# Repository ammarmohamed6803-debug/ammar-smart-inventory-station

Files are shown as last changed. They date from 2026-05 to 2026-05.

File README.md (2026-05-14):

📦 Handmade Heroes Inventory Station

A standalone IoT warehouse terminal built on ESP32 — scan, log, and sync inventory in real time without a computer.
🧾 Overview
The Handmade Heroes Inventory Station is a physical inventory management terminal designed for a small cosmetics warehouse. Workers tap their RFID cards, type a product code on a keypad, and log stock movements — all tracked per batch and synced live to Google Sheets.
Built entirely on an ESP32 DevKit V1, with no PC required on the warehouse floor.

✨ Features

🔖 RFID worker authentication — each worker taps their card to start a session
📦 Per-batch inventory tracking — store, ship, or add leftovers per batch number
🔁 Offline queue — transactions saved to flash if WiFi is down, auto-synced on reconnect
📊 Google Sheets integration — every transaction logs to a live spreadsheet via Apps Script
🌐 Web admin panel — edit the product list from any browser on the same network, no reflashing needed
🔒 Supervisor mode — Ammar, Aqilah, and Adi have elevated access to view stock and sync queue
↩️ Undo — reverse the last transaction (reflected on both device and sheet)
🛡️ Stock protection — can't delete a product that still has stock via the web admin
💾 Persistent storage — inventory state survives power cuts (LittleFS binary file)
⏱️ Auto session timeout — 30-minute idle timeout for security

🛠️ Hardware
ComponentDetailsMicrocontrollerESP32 DevKit V1 (30-pin)RFID ReaderRC522 (SPI)Display20×4 I2C LCD (address 0x27)Keypad4×4 matrix keypadLEDsGreen (GPIO 2), Red (GPIO 16)I2C ExpanderPCF8574 (for LCD backpack)
Pin Mapping
RC522 (SPI)
RC522ESP32SSGPIO 5RSTGPIO 4MOSIGPIO 23MISOGPIO 19SCKGPIO 18
LCD I2C
SignalESP32SDAGPIO 21SCLGPIO 22
Keypad Rows/Cols
PinsRows13, 14, 27, 26Cols25, 33, 32, 15

🚀 Getting Started
1. Prerequisites
Install these libraries in Arduino IDE:

MFRC522
LiquidCrystal_I2C
Keypad
WiFiClientSecure
LittleFS (ESP32 built-in)
Preferences (ESP32 built-in)
WebServer (ESP32 built-in)

Board: ESP32 Dev Module via Arduino ESP32 board package
2. Configuration
Edit these lines at the top of the .ino before flashing:
cppconst char* WIFI_SSID     = "YourNetworkName";
const char* WIFI_PASSWORD = "YourPassword";
const char* SHEET_URL     = "https://script.google.com/macros/s/YOUR_SCRIPT_ID/exec";
3. Google Apps Script Setup

Open Google Sheets → create a new spreadsheet
Go to Extensions → Apps Script
Paste your Code.gs and deploy as a Web App

Execute as: Me
Access: Anyone

Copy the deployment URL into SHEET_URL

4. First Boot
On first boot the device will:

Write the default product list to /products.csv on LittleFS
Connect to WiFi and show the IP address on the LCD
Auto-flush any queued offline transactions
Show Station Ready

5. Web Admin — Adding / Editing Products

Note the IP shown on the LCD at boot (e.g. 192.168.1.45)
Open http://192.168.1.45 in any browser on the same network
Edit products in code|name|sku format, one per line
Hit Save & Reload

⚠️ You cannot remove a product that still has stock. Ship it out first.

👷 Worker Roles
NameRoleAmmarSupervisorAqilahSupervisorAdiSupervisorYettiWorkerStevenWorkerStaffWorker
Supervisors get an Admin Panel on login with options to view stock, sync the offline queue, and switch to work mode.

📋 Transaction Types
ActionDescriptionStorageNew stock arriving — enter batch, box color, box qty, piecesShippingStock going out — pick batch, enter pieces to deductAdd LeftoverAdd loose pieces to an existing batch

🔄 Offline Mode
If WiFi is down, transactions are saved to /queue.txt on LittleFS. They auto-flush to Google Sheets on next boot, or manually via the supervisor's Sync Queue option.

🔧 Factory Reset
To wipe all stored data, uncomment this in setup():
cppfactoryReset();
Flash once, then comment it out and reflash. The LCD will instruct you.

📊 Google Sheets Columns
ColumnFieldADate & TimeBProduct ID (SKU)CProduct NameDConditionEBox TypeFNo. of BoxesGNo. of PiecesHTotal QtyIPatch No. (Batch)JWorker Name

📝 Version History
VersionChangesv5Web admin panel, LittleFS batch persistence, undo syncs to Sheets, factory reset, stock protectionv4Per-batch tracking, offline queue, supervisor mode, NVS persistence

📄 License
MIT — free to use and modify. Credit appreciated.

🙏 Acknowledgements
Built for Handmade Heroes — a Malaysian handmade cosmetics brand. Designed to replace manual stock counting with a fast, reliable, offline-capable hardware terminal.

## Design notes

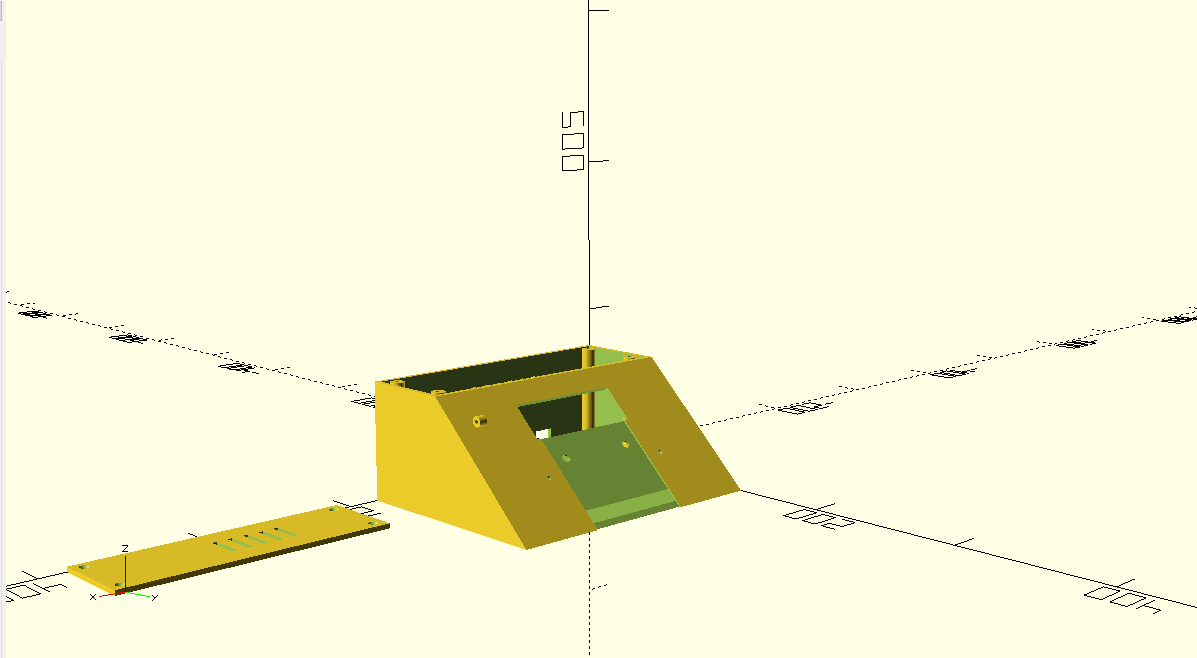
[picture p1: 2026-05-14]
3D design.png

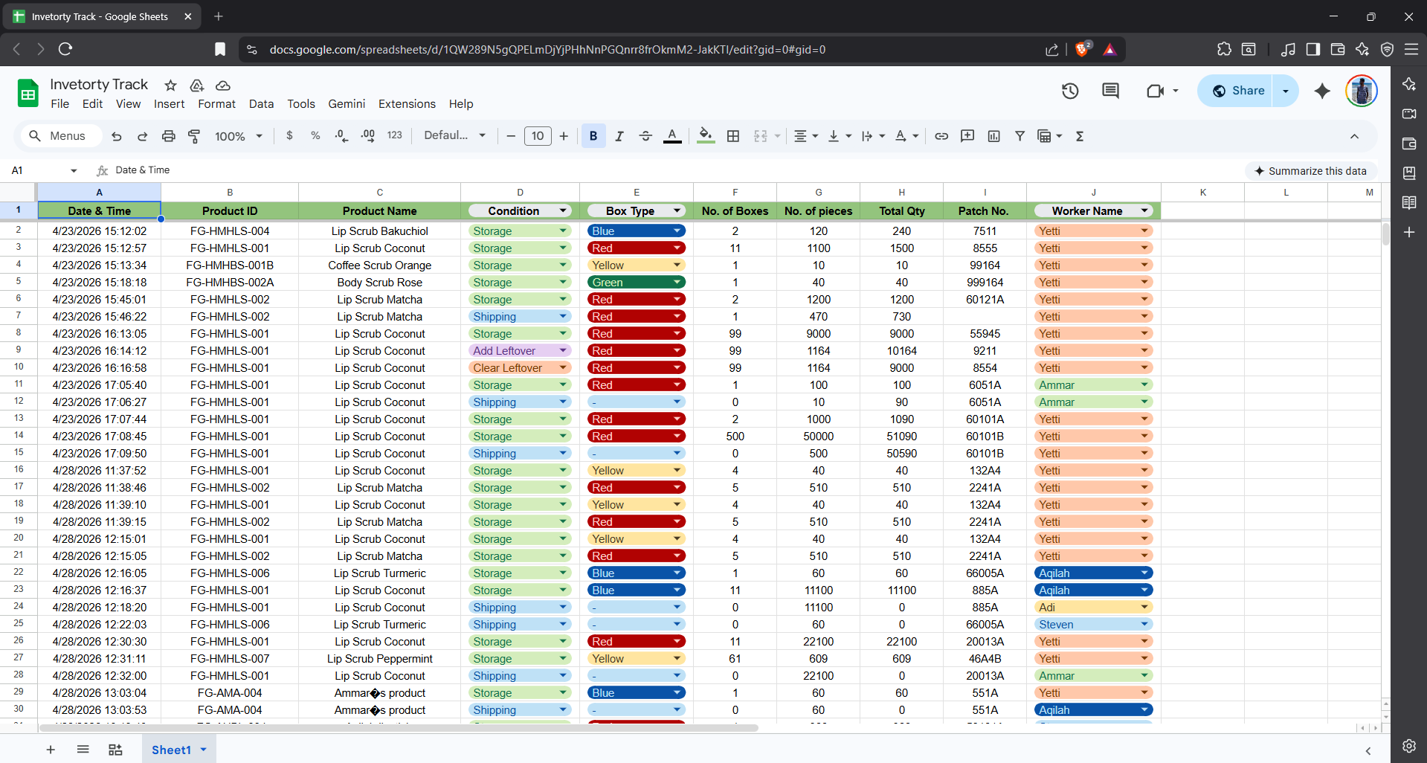
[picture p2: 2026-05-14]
google sheet.png

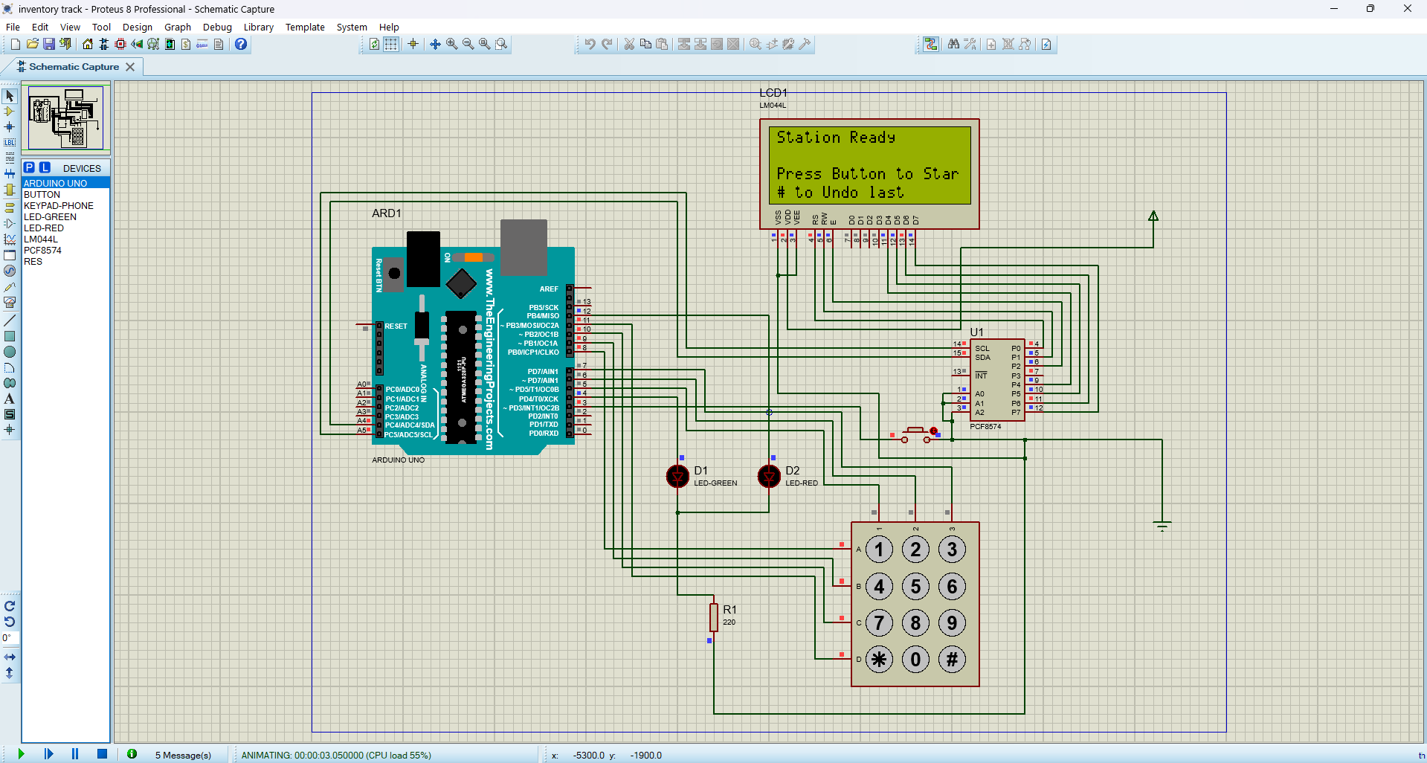
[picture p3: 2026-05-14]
circuit.png

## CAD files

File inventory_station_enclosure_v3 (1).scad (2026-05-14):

// ============================================================
// Handmade Heroes Inventory Station — Sloped Desktop Console
// v3 — cutouts done as vertical through-cuts (reliable on slopes)
// ============================================================
//
// RENDER_PART:
//   0 = both (preview)
//   1 = body only (export as body.stl)
//   2 = lid only  (export as lid.stl)
// ============================================================

RENDER_PART = 0;

// --- Wall & fit ---
wall      = 3.0;
lid_gap   = 0.3;

// --- Outer dimensions ---
box_w      = 180;
base_depth = 140;
top_depth  = 60;
box_h      = 75;

// --- 20x4 I2C LCD (standard module) ---
lcd_pcb_w          = 98;
lcd_pcb_h          = 60;
lcd_viewing_w      = 76;
lcd_viewing_h      = 26;
lcd_hole_spacing_w = 93;
lcd_hole_spacing_h = 55;
lcd_hole_dia       = 3.2;

// --- 4x4 keypad ---
keypad_w = 70;
keypad_h = 77;

// --- RC522 ---
rc522_hole_spacing_w = 55;
rc522_hole_spacing_h = 34;
rc522_hole_dia       = 2.8;

// --- ESP32 ---
esp32_hole_spacing_w = 48;
esp32_hole_spacing_h = 25;
esp32_hole_dia       = 2.8;

// --- LEDs & jack ---
led_dia         = 5.2;
barrel_jack_dia = 8.5;
usb_slot_w      = 14;
usb_slot_h      = 9;

// --- Lid ---
lid_screw_dia  = 3.2;
lid_post_dia   = 9;
lid_post_inset = 7;

$fn = 48;

// ============================================================
// SLOPE MATH
// Front face: runs from (y=top_depth, z=box_h) at TOP,
//             down to (y=base_depth, z=0) at BOTTOM
// So as you go DOWN in Z, you go further FORWARD in Y.
// Parametric position along the slope at height z:
//   y(z) = base_depth - (base_depth - top_depth) * (z / box_h)
// ============================================================

// Slope length (for reference)
slope_dy  = base_depth - top_depth;
slope_dz  = box_h;
slope_len = sqrt(slope_dy*slope_dy + slope_dz*slope_dz);

// The angle of the front face from VERTICAL (how much it leans forward)
// tan(lean) = slope_dy / slope_dz
lean_deg = atan(slope_dy / slope_dz);   // ~47° with current values

// Function: given a height z on the slope, return the y-coordinate of
// the front face at that height.
function front_y(z) = base_depth - (slope_dy) * (z / box_h);

// ============================================================
// WEDGE SOLID
// ============================================================
module wedge_solid(w, bd, td, h) {
    polyhedron(
        points = [
            [0, 0, 0],[w, 0, 0],[w, bd, 0],[0, bd, 0],
            [0, 0, h],[w, 0, h],[w, td, h],[0, td, h]
        ],
        faces = [
            [0,1,2,3],[7,6,5,4],[0,4,5,1],
            [2,6,7,3],[0,3,7,4],[1,5,6,2]
        ]
    );
}

// ============================================================
// CUT-THROUGH-SLOPE HELPER
// Places a vertical cylinder/box at (x, z_on_slope) that punches
// cleanly through the sloped front face.
// The cut is made as a shape extending in the Y direction (horizontal),
// rotated so its axis is perpendicular to the slope. This gives a
// clean round hole on the slope face.
// ============================================================
module perp_cut_cylinder(x, z, dia, depth = 20) {
    // Position at the front face at height z
    y = front_y(z);
    translate([x, y, z])
        rotate([-(90 - lean_deg), 0, 0])   // tilt so cut axis is perpendicular to slope
            translate([0, 0, -depth/2])
                cylinder(d = dia, h = depth);
}

module perp_cut_box(x, z, w, h, depth = 20) {
    // Rectangular cut through the slope face at (x, z), sized w by h
    // on the slope plane.
    y = front_y(z);
    translate([x, y, z])
        rotate([-(90 - lean_deg), 0, 0])
            translate([-w/2, -h/2, -depth/2])
                cube([w, h, depth]);
}

// ============================================================
// BODY
// ============================================================
module body() {
    difference() {
        wedge_solid(box_w, base_depth, top_depth, box_h);

        // Hollow interior
        // The front face leans, so simply insetting in Y by `wall` isn't enough —
        // we need to inset perpendicular to the sloped face.
        // Perpendicular Y-offset = wall / cos(lean_deg)
        front_inset = wall / cos(lean_deg);
        translate([wall, wall, wall])
            wedge_solid(box_w - 2*wall,
                        base_depth - wall - front_inset,
                        top_depth  - wall - front_inset,
                        box_h - wall);

        // Top opening for lid
        translate([wall + lid_gap, wall + lid_gap, box_h - 3])
            cube([box_w - 2*wall - 2*lid_gap,
                  top_depth - 2*wall - 2*lid_gap, 4]);

        // Front face cutouts
        front_cutouts();

        // Back wall cutouts
        back_cutouts();
    }

    internal_standoffs();
    lid_posts();
}

// ============================================================
// FRONT FACE CUTOUTS
// Layout by Z-height on the slope:
//   box_h = 75mm total
//   LCD window center at z = 55
//   LEDs at z = 35
//   Keypad center at z = 20
// ============================================================
module front_cutouts() {
    center_x = box_w / 2;

    // --- LCD viewing window (rectangle) ---
    lcd_center_z = 55;
    perp_cut_box(center_x, lcd_center_z, lcd_viewing_w, lcd_viewing_h, 40);

    // --- LCD 4 mounting holes (corners of the PCB) ---
    // On-slope offsets from the LCD center
    for (dx = [-lcd_hole_spacing_w/2, lcd_hole_spacing_w/2])
        for (dz = [-lcd_hole_spacing_h/2, lcd_hole_spacing_h/2])
            perp_cut_cylinder(center_x + dx, lcd_center_z + dz,
                              lcd_hole_dia, 40);

    // --- LEDs: green (left) and red (right) ---
    led_z = 35;
    perp_cut_cylinder(center_x - 25, led_z, led_dia, 40);
    perp_cut_cylinder(center_x + 25, led_z, led_dia, 40);

    // --- Keypad through-hole for the whole panel area ---
    // We'll make this a shallow recess + ribbon slot, not a full cutout
    // (the keypad is adhesive on the surface, only the ribbon cable needs to go through)
    keypad_center_z = 20;

    // Shallow recess for keypad adhesive (1mm deep into surface)
    keypad_recess(center_x, keypad_center_z);

    // Ribbon cable pass-through slot (small rectangle)
    perp_cut_box(center_x, keypad_center_z + keypad_h/2 - 3, 24, 4, 40);
}

// Shallow 1mm keypad recess (surface depression, not through)
module keypad_recess(cx, cz) {
    y = front_y(cz);
    translate([cx, y, cz])
        rotate([-(90 - lean_deg), 0, 0])
            translate([-keypad_w/2, -keypad_h/2, -1])
                cube([keypad_w, keypad_h, 1.05]);
}

// ============================================================
// BACK WALL
// ============================================================
module back_cutouts() {
    // USB slot (left)
    translate([box_w * 0.25, wall/2, box_h * 0.25])
        cube([usb_slot_w, wall + 2, usb_slot_h], center = true);

    // Barrel jack (right)
    translate([box_w * 0.78, wall/2, box_h * 0.45])
        rotate([90, 0, 0])
            cylinder(d = barrel_jack_dia, h = wall + 4, center = true);

    // Vents
    for (i = [0:5])
        translate([box_w * 0.30 + i * 10, wall/2, box_h * 0.72])
            cube([3, wall + 4, 14], center = true);
}

// ============================================================
// INTERNAL STANDOFFS
// ============================================================
module internal_standoffs() {
    post_dia = 6.5;

    // RC522 on inside of right wall
    rc522_cy = base_depth * 0.55;
    rc522_cz = box_h * 0.5;
    h_off = 5;

    for (dy = [-rc522_hole_spacing_h/2, rc522_hole_spacing_h/2])
        for (dz = [-rc522_hole_spacing_w/2, rc522_hole_spacing_w/2])
            translate([box_w - wall - h_off, rc522_cy + dy, rc522_cz + dz])
                rotate([0, 90, 0])
                    difference() {
                        cylinder(d = post_dia, h = h_off);
                        cylinder(d = rc522_hole_dia - 0.3, h = h_off + 1);
                    }

    // ESP32 on floor, back-left
    esp32_cx = box_w * 0.25;
    esp32_cy = 22;
    esp32_post_h = 6;

    for (dx = [-esp32_hole_spacing_w/2, esp32_hole_spacing_w/2])
        for (dy = [-esp32_hole_spacing_h/2, esp32_hole_spacing_h/2])
            translate([esp32_cx + dx, esp32_cy + dy, wall])
                difference() {
                    cylinder(d = post_dia, h = esp32_post_h);
                    cylinder(d = esp32_hole_dia - 0.3, h = esp32_post_h + 1);
                }
}

// ============================================================
// LID CORNER POSTS
// ============================================================
module lid_posts() {
    post_h = box_h - 3;
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

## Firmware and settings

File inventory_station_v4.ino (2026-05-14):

#include <SPI.h>
#include <MFRC522.h>
#include <Wire.h>
#include <LiquidCrystal_I2C.h>
#include <Keypad.h>
#include <WiFi.h>
#include <HTTPClient.h>
#include <WiFiClientSecure.h>
#include <LittleFS.h>
#include <Preferences.h>

// ============================================================
//  Handmade Heroes Inventory Station — v4 (MERGED)
//  Board: ESP32 DevKit V1 (30-pin)
//  Features:
//   - Per-batch inventory tracking (Storage / Ship / Add Leftover)
//   - Batch-aware shipping & leftover (pick from existing batches)
//   - Inventory + batches persist across reboot (Preferences/NVS)
//   - Offline queue on LittleFS, auto-flush on boot
//   - Supervisor mode (Aqilah, Adi) with admin panel
//   - Products loaded from /products.csv on LittleFS (editable)
// ============================================================

// --- WiFi ---
const char* WIFI_SSID     = "SparkeLabs_2.4GHz";
const char* WIFI_PASSWORD = "12345678";

// --- Google Apps Script URL ---
const char* SHEET_URL = "https://script.google.com/macros/s/AKfycbym5JZwn9BIzqOETfA4Sa0kmPfgXFmbDQrbwtvMrDbQJu0BIF-1C5gdSOyR9KzuFthaTQ/exec";

// --- RC522 RFID (SPI) ---
#define RC522_SS   5
#define RC522_RST  4
MFRC522 rfid(RC522_SS, RC522_RST);

// --- LCD 20x4 (I2C @ 0x27) ---
LiquidCrystal_I2C lcd(0x27, 20, 4);

// --- LEDs ---
const int GREEN_LED_PIN = 2;
const int RED_LED_PIN   = 16;

// --- 4x4 Keypad ---
const byte ROWS = 4, COLS = 4;
char keys[ROWS][COLS] = {
  {'1','2','3','A'},
  {'4','5','6','B'},
  {'7','8','9','C'},
  {'*','0','#','D'}
};
byte rowPins[ROWS] = {13, 14, 27, 26};
byte colPins[COLS] = {25, 33, 32, 15};
Keypad keypad = Keypad(makeKeymap(keys), rowPins, colPins, ROWS, COLS);

// --- Preferences (NVS) ---
Preferences prefs;

// ============================================================
//  WORKER DATABASE — Aqilah (1) and Adi (5) are SUPERVISORS
// ============================================================
const int NUM_WORKERS = 6;
byte workerUIDs[NUM_WORKERS][7] = {
  {0x19, 0x82, 0xBA, 0x11, 0x00, 0x00, 0x00}, // Ammar   (supervisor)
  {0x04, 0xC1, 0x6A, 0x2E, 0x32, 0x02, 0x89}, // Aqilah  (supervisor)
  {0x04, 0x91, 0x2D, 0x3D, 0x32, 0x02, 0x89}, // Yetti
  {0x04, 0x31, 0x58, 0xBB, 0x31, 0x02, 0x89}, // Steven
  {0x04, 0xC1, 0x03, 0xF8, 0x31, 0x02, 0x89}, // Staff
  {0x04, 0xB1, 0xF5, 0xAA, 0x31, 0x02, 0x89}  // Adi     (supervisor)
};
byte   workerUIDSizes[NUM_WORKERS] = {4, 7, 7, 7, 7, 7};
String workerNames[NUM_WORKERS]    = {"Ammar","Aqilah","Yetti","Steven","Staff","Adi"};
bool   isSupervisor[NUM_WORKERS]   = {true, true, false, false, false, true};
int currentWorker = -1;

// ============================================================
//  PRODUCT DATABASE
//  100 max slots, loaded from /products.csv on LittleFS
//  First boot writes defaults to file if missing.
// ============================================================
const int MAX_PRODUCTS = 90;
int NUM_PRODUCTS = 86;

String productCodes[MAX_PRODUCTS];
String productNames[MAX_PRODUCTS];
String productSKUs[MAX_PRODUCTS];

const char* defaultProducts[] = {
  "001A|Lip Scrub Coconut|FG-HMHLS-001",
  "002A|Lip Scrub Matcha|FG-HMHLS-002",
  "004A|Lip Scrub Bakuchiol|FG-HMHLS-004",
  "006A|Lip Scrub Turmeric|FG-HMHLS-006",
  "007A|Lip Scrub Peppermint|FG-HMHLS-007",
  "001B|Coffee Scrub Orange|FG-HMHBS-001B",
  "02AB|Body Scrub Rose|FG-HMHBS-002A",
  "04DC|Clay Mask GreenTea|FG-HMHFM-004",
  "02AC|Gel Mask Jasmine|FG-HMHGM-002",
  "01DA|DryShampoo Med-Dark|FG-HMHDS-001",
  "02DA|DryShampoo Lt-Med|FG-HMHDS-002",
  "03DA|DryShampoo Rosemary Dark|FG-HMHDS-003",
  "04DA|DryShampoo Rosemary Lt|FG-HMHDS-004",
  "02BB|Nipple Balm|FG-HMHNB-002",
  "01DB|Diaper Balm|FG-HMHDB-001",
  "01AA|Lip Mask AllNighter|FG-HMHLM-001",
  "02AA|Lip Mask Bakuchiol|FG-HMHLM-002",
  "05AA|Lip Butter SoftPink|FG-HMHLM-005",
  "03BA|Lip Dew Mood|FG-HMHLT-003A",
  "06BA|Lip Dew Classic|FG-HMHLT-006A",
  "07BA|Lip Dew CottageCore 1.3g|FG-HMHLT-007",
  "7BAA|Lip Dew CottageCore 10ml|FG-HMHLT-007A",
  "02BA|Lip Dew Spirited|FG-HMHLB-002A",
  "001C|SnowShroom HA Serum|FG-HMHFS-001",
  "003C|Bakuchiol Oil 22ml|FG-HMHFS-003",
  "03CB|Bakuchiol Oil 10ml|FG-HMHFS-003B",
  "004C|Bakuchiol FirmSerum|FG-HMHFS-004",
  "005C|Squalane Face Oil|FG-HMHFS-005",
  "006C|SuperGlow VitC Oil|FG-HMHFS-006",
  "01CC|Oat Cuticle Oil|FG-HMHCO-001",
  "01CA|Eyelash Serum|FG-HMHES-001",
  "02CA|Eyebrow Serum|FG-HMHES-002",
  "03CA|UnderEye Espresso|FG-HMHES-003",
  "1AA0|LipOil SuperGlaze 5ml|FG-HMHLO-001",
  "1AAA|LipOil SuperGlaze 1ml|FG-HMHLO-001A",
  "2AA0|LipOil SugarPeach 5ml|FG-HMHLO-002",
  "2AAA|LipOil SugarPeach 1ml|FG-HMHLO-002A",
  "3AA0|LipOil Caramel 5ml|FG-HMHLO-003",
  "3AAA|LipOil Caramel 1ml|FG-HMHLO-003A",
  "4AA0|LipOil SweetBeet 5ml|FG-HMHLO-004",
  "4AAA|LipOil SweetBeet 1ml|FG-HMHLO-004A",
  "5AA0|LipOil VitC Turmeric|FG-HMHLO-005",
  "6AA0|LipOil Moonshine 5ml|FG-HMHLO-006",
  "6AAA|LipOil Moonshine 1ml|FG-HMHLO-006A",
  "7AA0|LipOil Ripe Cherry|FG-HMHLO-007",
  "1AB0|Face Mist Jasmine 66ml|FG-HMHMF-001",
  "1ABA|Face Mist Jasmine|FG-HMHMF-001A",
  "1CA0|Peppermint FootCream|FG-HMHFC-001",
  "2CA0|TeaTree FootCream|FG-HMHFC-002",
  "CC01|Natural Deo Unscent|FG-HMHSD-001",
  "AC01|Hair Tonic Thrive|FG-HMHHT-001",
  "5BB0|HBS Hyaluronic Acid|FG-HBS-005",
  "6BB0|HBS Niacinamide 12%|FG-HBS-006",
  "7BB0|HBS Niacinamide 20%|FG-HBS-007",
  "8BB0|HBS Vitamin C|FG-HBS-008",
  "9BB0|HBS Salicylic Acid|FG-HBS-009",
  "10BB|HBS Caffeine Eye|FG-HBS-010",
  "C010|Oat Cleansing Oil|FG-MOC-001",
  "B010|Micellar Water|FG-MMW-001",
  "CB01|VitF Cleansing Balm|FG-MCB-001",
  "AB01|AB Niacinamide 12%|FG-ABS-001",
  "AB02|AB Squalane|FG-ABS-002",
  "AB03|AB Vitamin C Serum|FG-ABS-003",
  "AB04|AB Hyaluronic Acid|FG-ABS-004",
  "AB06|AB Niacinamide 20%|FG-ABS-006",
  "AB07|AB Salicylic Acid|FG-ABS-007",
  "BB01|JP Deo FragranceFree|FG-JPSD-001",
  "BB02|JP Deo Zen AF|FG-JPSD-002",
  "BB03|JP Deo Coconut Van|FG-JPSD-003",
  "AA01|GiftBox LipCare|FG-HMHGB-001",
  "AA02|GiftBox LipBrighten|FG-HMHGB-002",
  "AA03|GiftBox LipPerfect|FG-HMHGB-003",
  "AA04|GiftBox DewySkin Kit|FG-HMHGB-004",
  "AA05|GiftBox LipOil Set|FG-HMHGB-005",
  "AA06|GiftBox MiniLipOil|FG-HMHGB-006",
  "AA07|Lip Exfoliate Brush|FG-HMHGB-007",
  "AA08|GiftBox Lash&Brow|FG-HMHGB-008",
  "AA12|Pumice Foot File|FG-HMHGB-012",
  "AA13|MicroGlass FootFile|FG-HMHGB-013",
  "AA14|Exfoliating Gloves|FG-HMHGB-014",
  "AA15|Cozy Socks Green|FG-HMHGB-015",
  "AA16|Cozy Gloves Green|FG-HMHGB-016",
  "AA17|Lip Brush Yellow|FG-HMHGB-017",
  "CA01|FaceLift Belt Blue|FG-HBGB-001",
  "CA02|FaceLift Belt Beige|FG-HBGB-002",
  "CA03|FaceLift Belt Pink|FG-HBGB-003"
};
const int DEFAULT_PRODUCT_COUNT = 86;

// ============================================================
//  BATCH DATA MODEL
//  Fixed-size struct so we can persist with prefs.putBytes()
//  batchNo[0] == '\0' means slot is unused
// ============================================================
const int MAX_BATCHES = 15;
const int BATCH_NO_LEN = 13;   // 12 chars + null terminator

struct BatchInfo {
  char batchNo[BATCH_NO_LEN];   // empty C-string = unused
  int  boxes[5];                // [unused, Red, Blue, Green, Yellow]
  int  pieces;                  // total pieces in this batch
};

BatchInfo batches[MAX_PRODUCTS][MAX_BATCHES];

// --- Offline queue counter ---
int queueCount = 0;

// ============================================================
//  STATE MACHINE
// ============================================================
enum State {
  STATE_IDLE,
  STATE_SUPERVISOR_MENU,
  STATE_ENTER_ID,
  STATE_CONFIRM_PRODUCT,
  STATE_SELECT_ACTION,
  STATE_ENTER_BATCH,
  STATE_SELECT_BATCH,
  STATE_SHOW_BATCH_DETAIL,
  STATE_SELECT_BOX,
  STATE_ENTER_BOX_QTY,
  STATE_ENTER_PIECES,
  STATE_CONFIRM,
  STATE_INVENTORY_SUMMARY
};
State currentState = STATE_IDLE;

// --- Session data ---
String inputBuffer        = "";
String currentProductCode = "";
int    currentProductIdx  = -1;
int    currentAction      = 0;     // 1=Store, 2=Ship, 3=Add Leftover
int    currentBoxColor    = 0;
int    boxQty  = 0;
int    pieceQty = 0;
String batchNo  = "";
int    selectedBatchIdx = -1;
int    batchPage = 0;

// --- Undo buffer ---
String lastTransaction = "None";
int    lastPIdx        = -1;
int    lastAction      = 0;
int    lastBoxColor    = 0;
int    lastBoxQty      = 0;
int    lastPieceQty    = 0;
int    lastBatchIdx    = -1;
bool   lastBatchWasNew = false;
String lastWorkerName  = "";
String lastBatch       = "";

// --- Idle timeout ---
unsigned long lastActivityMs = 0;
const unsigned long IDLE_TIMEOUT_MS = 30UL * 60UL * 1000UL;

// --- Prototypes ---
void showIdleScreen();
void promptProductID();
void showProductConfirm();
void promptAction();
void promptBatch();
void showBatchSelector();
void showBatchDetail();
void promptBoxColor();
void promptBoxQty();
void promptPieces();
void showConfirmation();
void saveTransaction();
void showInventorySummary(int);
void errorFlash(String);
void resetSession();
void handleUndo();
void showSupervisorMenu();
void adminViewStock();
void adminFlushQueue();
void adminViewQueue();
void saveBatchState();
void loadBatchState();
void saveProductsToFile();
void loadProductsFromFile();
void loadDefaultProducts();
void queueTransaction(String payload);
void flushQueue();
int  countQueuedItems();
int  findProductIndex(String code);
int  findWorkerIndex(byte* uid, byte size);
int  findBatchIndex(int p, String bn);
int  findFreeBatchSlot(int p);
int  countActiveBatches(int p);
int  nthActiveBatch(int p, int n);
int  totalProductPieces(int p);
int  totalProductBoxes(int p, int color);
void cleanupEmptyBatches(int p);
bool sendToSheet(String payload);
String boxColorName(int c);
String actionName(int a);

// ============================================================
//  HTTP
// ============================================================
bool sendToSheet(String payload) {
  WiFiClientSecure client;
  client.setInsecure();
  HTTPClient https;
  https.setTimeout(10000);
  https.setFollowRedirects(HTTPC_DISABLE_FOLLOW_REDIRECTS);
  if (!https.begin(client, SHEET_URL)) return false;
  https.addHeader("Content-Type", "application/json");
  int code = https.POST(payload);
  https.end();
  Serial.print("HTTP: "); Serial.println(code);
  return (code == 200 || code == 302);
}

// ============================================================
//  OFFLINE QUEUE (LittleFS)
// ============================================================
void queueTransaction(String payload) {
  File f = LittleFS.open("/queue.txt", FILE_APPEND);
  if (f) {
    f.println(payload);
    f.close();
    queueCount++;
    Serial.println("Queued offline (Q:" + String(queueCount) + ")");
  }
}

int countQueuedItems() {
  File f = LittleFS.open("/queue.txt", FILE_READ);
  if (!f) return 0;
  int count = 0;
  while (f.available()) {
    String line = f.readStringUntil('\n');
    line.trim();
    if (line.length() > 2) count++;
  }
  f.close();
  return count;
}

void flushQueue() {
  if (WiFi.status() != WL_CONNECTED) return;
  File f = LittleFS.open("/queue.txt", FILE_READ);
  if (!f) return;

  String lines[50];
  int total = 0;
  while (f.available() && total < 50) {
    String line = f.readStringUntil('\n');
    line.trim();
    if (line.length() > 2) lines[total++] = line;
  }
  f.close();

  if (total == 0) return;

  String failedLines[50];
  int failed = 0;

  for (int i = 0; i < total; i++) {
    lcd.clear();
    lcd.setCursor(0,0); lcd.print("Syncing " + String(i+1) + "/" + String(total));
    if (!sendToSheet(lines[i])) {
      failedLines[failed++] = lines[i];
    }
    lcd.init(); lcd.backlight();
  }

  LittleFS.remove("/queue.txt");
  if (failed > 0) {
    File fw = LittleFS.open("/queue.txt", FILE_WRITE);
    for (int i = 0; i < failed; i++) fw.println(failedLines[i]);
    fw.close();
  }
  queueCount = failed;
}

// ============================================================
//  BATCH STATE PERSISTENCE (Preferences/NVS)
// ============================================================
void saveBatchState() {
  prefs.begin("inv", false);
  prefs.putInt("numProd", NUM_PRODUCTS);
  prefs.putBytes("batches", batches, sizeof(batches));
  prefs.end();
  Serial.println("Batch state saved to flash");
}

void loadBatchState() {
  prefs.begin("inv", true);
  int savedCount = prefs.getInt("numProd", 0);
  if (savedCount > 0) {
    size_t got = prefs.getBytes("batches", batches, sizeof(batches));
    Serial.println("Batch state loaded (" + String(got) + " bytes)");
  } else {
    Serial.println("No saved batch state — starting fresh");
    memset(batches, 0, sizeof(batches));
  }
  prefs.end();
}

// ============================================================
//  PRODUCT LIST PERSISTENCE (LittleFS)
// ============================================================
void loadDefaultProducts() {
  NUM_PRODUCTS = DEFAULT_PRODUCT_COUNT;
  for (int i = 0; i < DEFAULT_PRODUCT_COUNT; i++) {
    String line = String(defaultProducts[i]);
    int p1 = line.indexOf('|');
    int p2 = line.indexOf('|', p1 + 1);
    productCodes[i] = line.substring(0, p1);
    productNames[i] = line.substring(p1 + 1, p2);
    productSKUs[i]  = line.substring(p2 + 1);
  }
}

void saveProductsToFile() {
  File f = LittleFS.open("/products.csv", FILE_WRITE);
  if (!f) return;
  for (int i = 0; i < NUM_PRODUCTS; i++) {
    f.println(productCodes[i] + "|" + productNames[i] + "|" + productSKUs[i]);
  }
  f.close();
  Serial.println("Products saved to LittleFS (" + String(NUM_PRODUCTS) + ")");
}

void loadProductsFromFile() {
  File f = LittleFS.open("/products.csv", FILE_READ);
  if (!f) {
    Serial.println("No products.csv — using defaults");
    loadDefaultProducts();
    saveProductsToFile();
    return;
  }
  int count = 0;
  while (f.available() && count < MAX_PRODUCTS) {
    String line = f.readStringUntil('\n');
    line.trim();
    if (line.length() < 5) continue;
    int p1 = line.indexOf('|');
    int p2 = line.indexOf('|', p1 + 1);
    if (p1 < 0 || p2 < 0) continue;
    productCodes[count] = line.substring(0, p1);
    productNames[count] = line.substring(p1 + 1, p2);
    productSKUs[count]  = line.substring(p2 + 1);
    count++;
  }
  f.close();
  NUM_PRODUCTS = count;
  Serial.println("Loaded " + String(NUM_PRODUCTS) + " products from LittleFS");
}

// ============================================================
//  SETUP
// ============================================================
void setup() {
  Serial.begin(115200);
  pinMode(GREEN_LED_PIN, OUTPUT);
  pinMode(RED_LED_PIN, OUTPUT);

  if (!LittleFS.begin(true)) {
    Serial.println("LittleFS failed!");
  }

  // Initialize batch slots empty
  memset(batches, 0, sizeof(batches));

  loadProductsFromFile();
  loadBatchState();
  queueCount = countQueuedItems();

  Wire.begin(21, 22);
  lcd.init();
  lcd.backlight();

  SPI.begin();
  rfid.PCD_Init();
  delay(50);

  lcd.clear();
  byte v = rfid.PCD_ReadRegister(rfid.VersionReg);
  if (v == 0x00 || v == 0xFF) {
    lcd.print("RC522 ERROR!");
    lcd.setCursor(0,1); lcd.print("Check SPI wiring");
    while (true) delay(1000);
  }
  lcd.print("RC522 OK | Prod:");
  lcd.print(NUM_PRODUCTS);
  delay(800);

  lcd.clear();
  lcd.setCursor(0,0); lcd.print("Connecting WiFi...");
  WiFi.begin(WIFI_SSID, WIFI_PASSWORD);
  unsigned long wifiStart = millis();
  while (WiFi.status() != WL_CONNECTED && millis() - wifiStart < 15000) {
    delay(300);
  }
  lcd.clear();
  if (WiFi.status() == WL_CONNECTED) {
    lcd.print("WiFi Connected!");
    lcd.setCursor(0,1); lcd.print(WiFi.localIP());
    if (queueCount > 0) {
      lcd.setCursor(0,2); lcd.print("Flushing Q:" + String(queueCount));
      delay(500);
      flushQueue();
    }
  } else {
    lcd.print("WiFi Failed!");
    lcd.setCursor(0,1); lcd.print("Offline mode");
  }
  delay(1200);

  lastActivityMs = millis();
  showIdleScreen();
}
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
